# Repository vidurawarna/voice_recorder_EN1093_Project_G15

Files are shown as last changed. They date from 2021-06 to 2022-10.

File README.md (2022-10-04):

# voice_recorder_EN1093_Project_G15
Simple Voice Recorder is a simple tool to record multiple voice tracks and then play them back. The purpose of this project is to create a Simple Voice Recorder using theories of signal processing and information theory. The main objectives of this project are to record and save multiple voice recordings, selectively playback the recordings, and do minor adjustments to their spectrum during playback. Signal processing like frequency scaling and signal enhancement with low pass, band pass, and high pass filtering is carried out by using  MATLAB as a testing tool. (Relevant MATLAB codes can be found in the report.) An ATmega 328p chip was programmed with AVR. In this project, 8bit PCM (Pulse Code Modulation) is used for ADC ( Analog to Digital Conversion) and Fast PWM (Pulse Width Modulation) is used for DAC ( Digital to Analog Conversion).

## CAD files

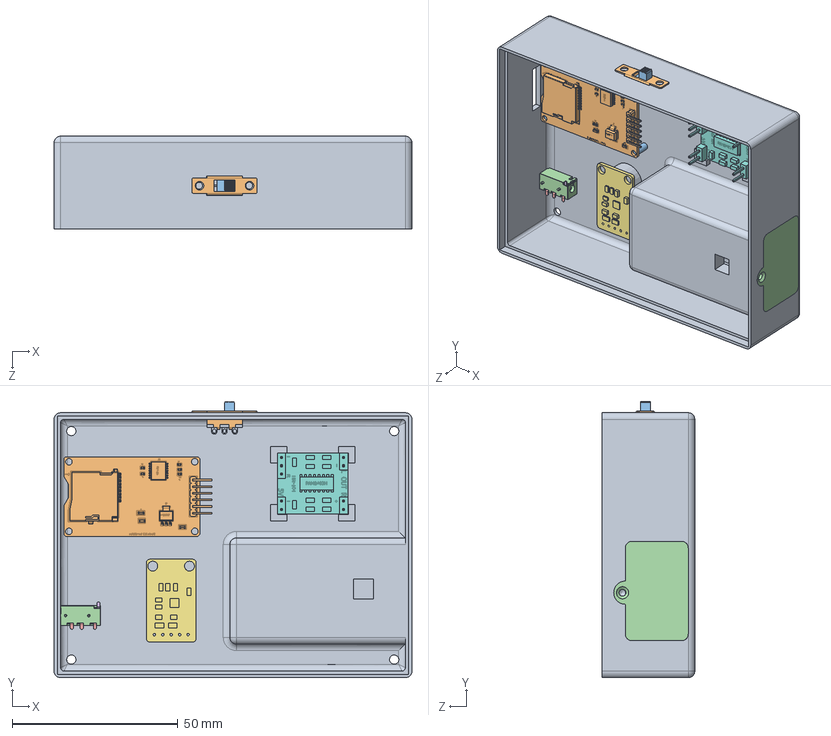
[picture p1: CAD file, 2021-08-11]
Enclosure and PCB/Enclosure Design/Assembled/Bottom Assembly.SLDASM
108.1 x 83.4 x 28.0 mm
Bottom Enclosure
Micro SD Module
SD Card Module Holder
PJ320A.STEP
PJ320D-Pin.STEP x 3
PJ320D-Pin-B.STEP
Microphone Module
Sound-Aplifier-Board-PAM8403-3W.stp
PCB.step
Housing.step
Switch.step
Battery Close Enclosure

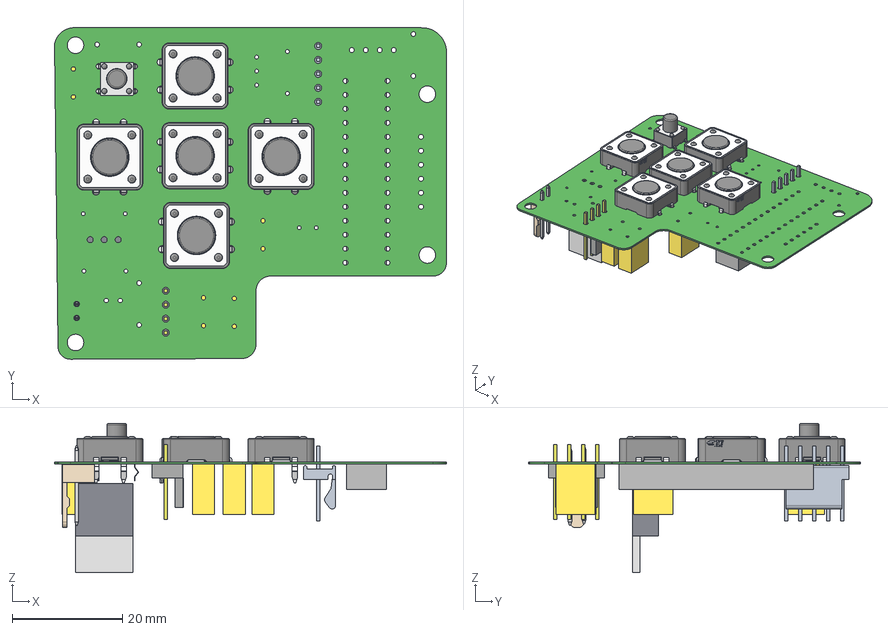
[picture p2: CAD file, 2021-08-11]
Enclosure and PCB/ALTIUM/EN1093 final/PCB_EN1093 1.step
71.2 x 60.2 x 27.1 mm
Extruded x 13
Switch_base
notches
Button
Pins
Panasonic
Leads x 5
Plastic x 5
Logo x 5
c-640456-5-aa-3d
6190xx11121_PIN x 2

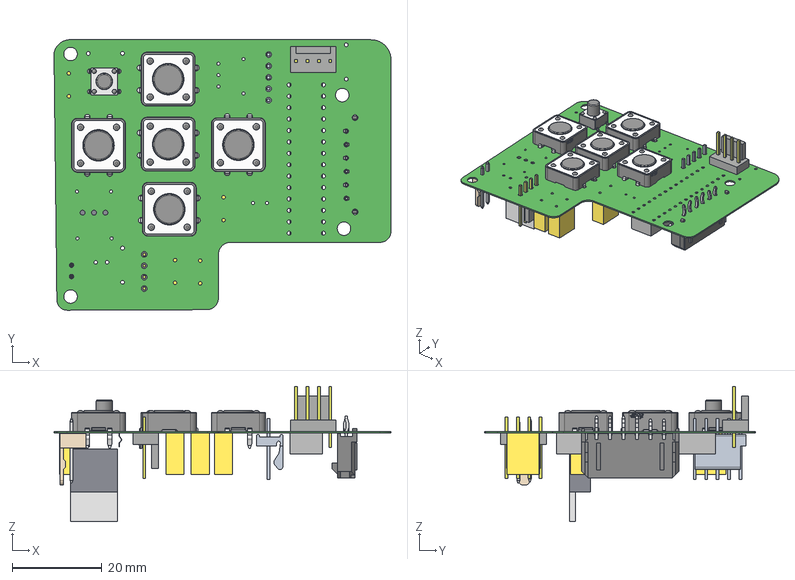
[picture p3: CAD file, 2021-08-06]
Enclosure and PCB/ALTIUM/EN1093 unrouted PCB for SolidWorks/PCB_EN1093.step
75.0 x 60.2 x 30.1 mm
6620xx11122_PIN x 6
Extruded x 19
Switch_base
notches
Button
Pins
Panasonic
Leads x 5
Plastic x 5
Logo x 5
c-640456-5-aa-3d
6190xx11121_PIN x 2

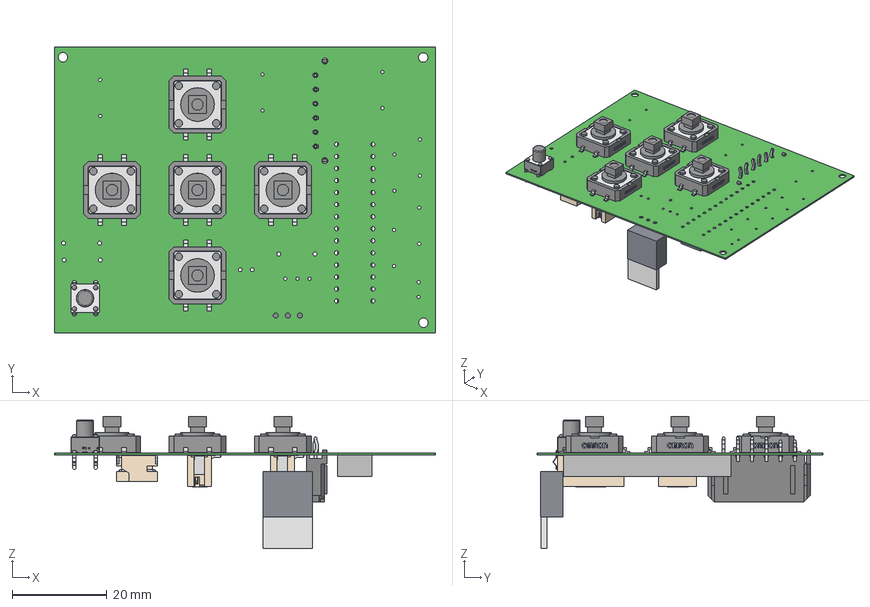
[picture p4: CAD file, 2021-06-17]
Enclosure and PCB/ALTIUM/EN1093 updated/PCB_EN1093_2.step
80.3 x 60.3 x 27.8 mm
Switch_base
notches
Button
Pins
Panasonic
IN x 5
Pads1 x 5
Pads2 x 5
Omron_Logo_Adjustable_Logo x 5
Extruded x 3
6203xx124022_PIN x 7
6203xx124022_Cap2
6203xx124022_PATTE x 4
6203xx124022_Cap1
6620xx11122_PIN x 6
6201xx131822_PIN x 8
6201xx131822_Solder_tab x 4

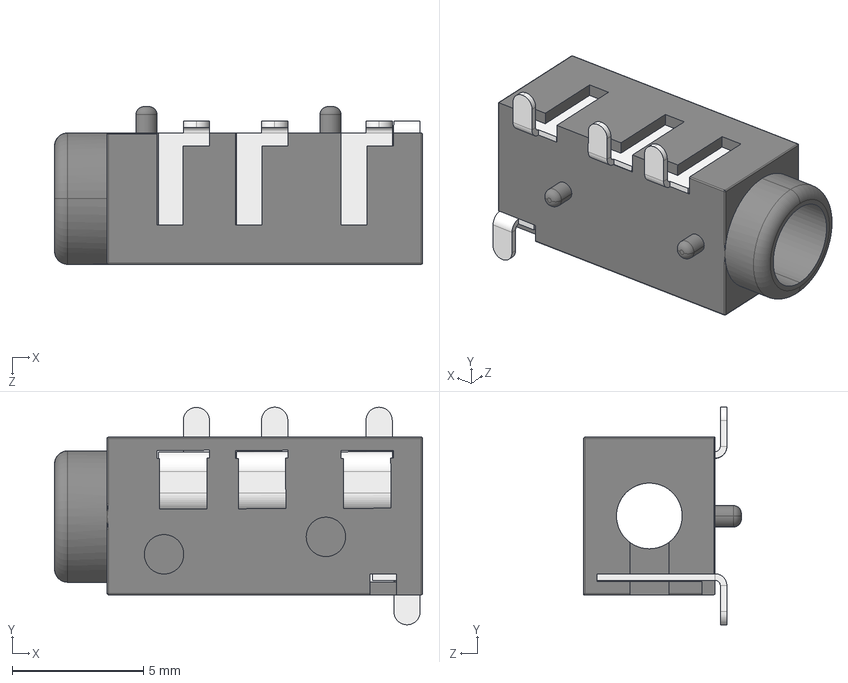
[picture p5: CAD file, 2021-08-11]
Enclosure and PCB/Enclosure Design/Modules/Jack.STEP
14.0 x 8.28 x 6.00 mm
PJ320A
PJ320D-Pin x 3
PJ320D-Pin-B

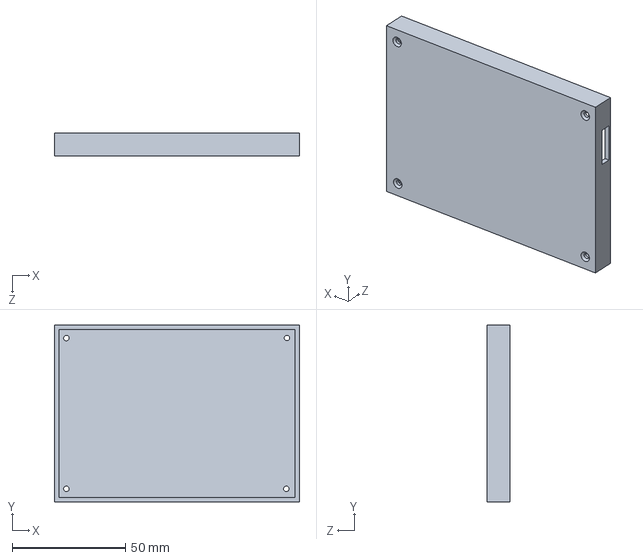
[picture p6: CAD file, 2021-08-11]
Enclosure and PCB/Enclosure Design/Enclosure/Bottom Enclosure.SLDPRT
108.1 x 78.0 x 10.0 mm

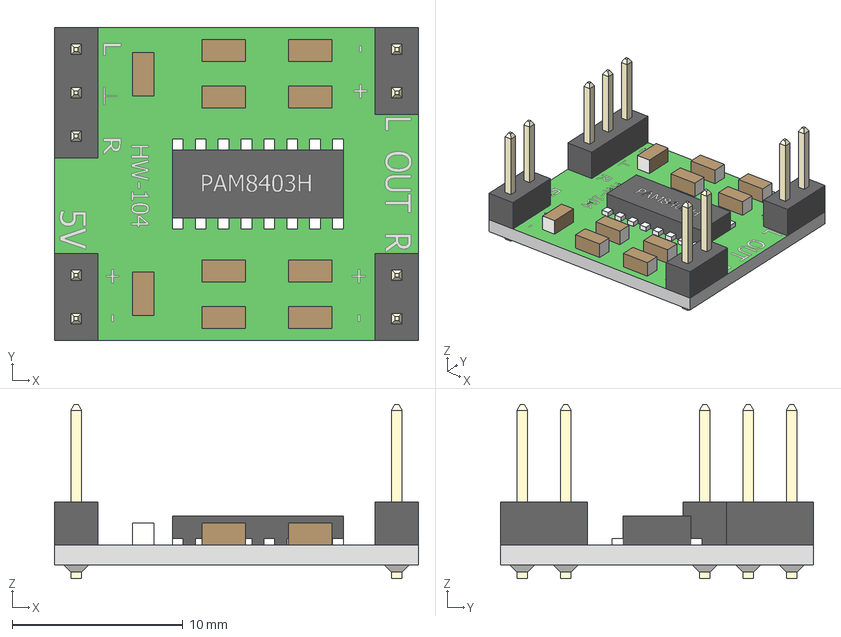
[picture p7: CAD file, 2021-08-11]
Enclosure and PCB/Enclosure Design/Modules/Sound Aplifier Board.stp
21.3 x 18.3 x 10.2 mm

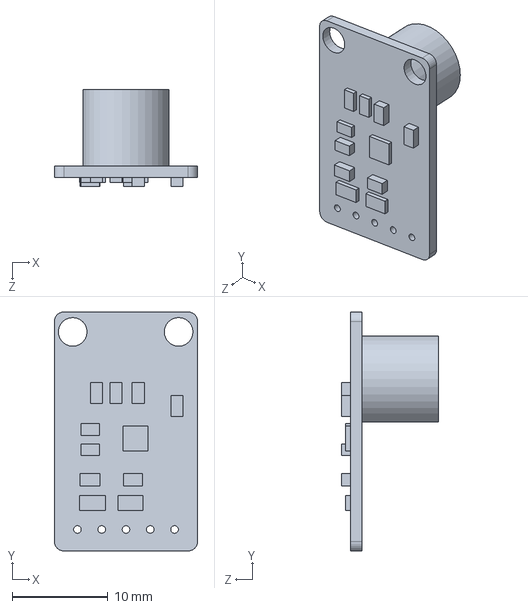
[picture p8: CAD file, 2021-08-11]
Enclosure and PCB/Enclosure Design/Modules/Microphone Module.SLDPRT
15.0 x 25.0 x 10.1 mm

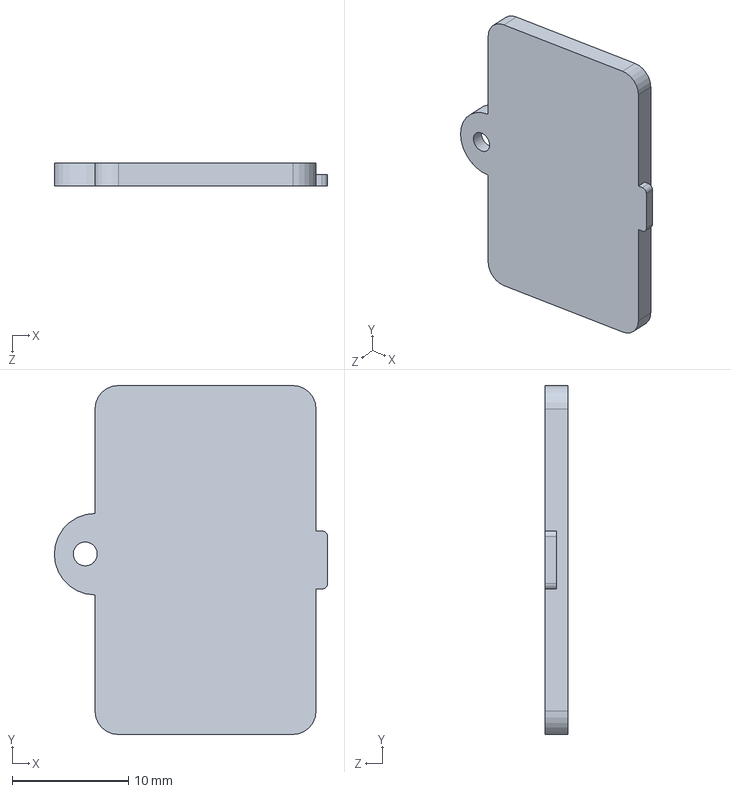
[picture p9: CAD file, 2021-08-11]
Enclosure and PCB/Enclosure Design/Enclosure/Battery Close Enclosure.SLDPRT
23.5 x 30.0 x 2.00 mm

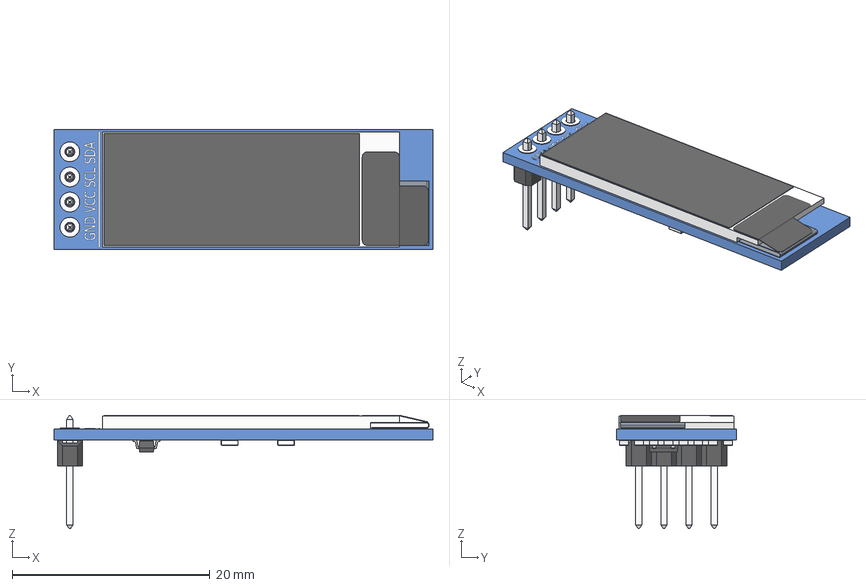
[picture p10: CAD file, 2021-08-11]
Enclosure and PCB/Enclosure Design/Modules/OLED LCD.stp
38.3 x 12.1 x 11.5 mm
OLED_0.91_128x32
Pin Header 4 x 1 TH 2.54mm Pitch
RESC-0603 x 13
2SD0601A

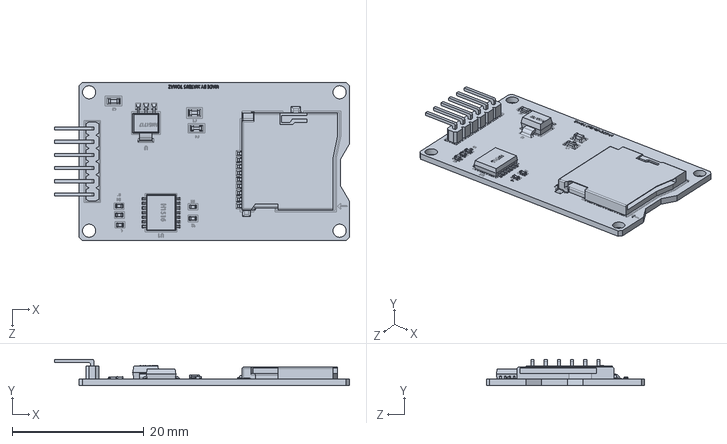
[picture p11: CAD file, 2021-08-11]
Enclosure and PCB/Enclosure Design/Modules/Micro SD Module.SLDPRT
44.7 x 4.00 x 24.0 mm

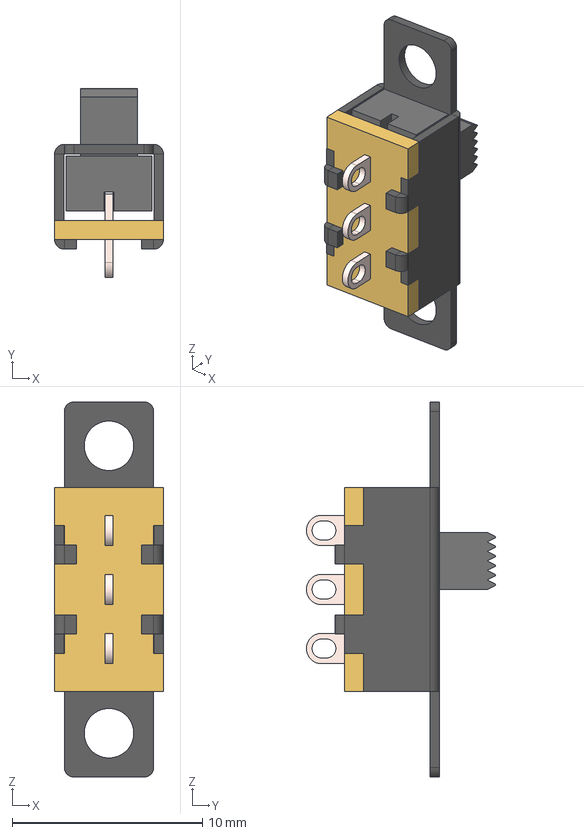
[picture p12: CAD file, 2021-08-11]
Enclosure and PCB/Enclosure Design/Modules/Mini Switch.step
5.72 x 9.94 x 19.7 mm
PCB
Housing
Switch

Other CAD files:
Enclosure and PCB/Enclosure Design/Enclosure/PCBEN10.step
Enclosure and PCB/ALTIUM/EN1093 final/PCB_EN1093.step
Enclosure and PCB/Enclosure Design/Enclosure/Key Pad Enclosure.SLDPRT
Enclosure and PCB/Enclosure Design/Enclosure/PCB_EN.step
Enclosure and PCB/Enclosure Design/Enclosure/Top Enclosure.SLDPRT
Enclosure and PCB/Enclosure Design/Modules/SD Card Module Holder.SLDPRT
Enclosure and PCB/Enclosure Design/Modules/Volume Knob Enclosure.SLDPRT

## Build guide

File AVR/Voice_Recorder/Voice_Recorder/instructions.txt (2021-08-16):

/*
 * instructions.txt
 *
 * Created: 6/15/2021 8:06:09 AM
 *  Author: Vidura
 */ 

[#] Conections:
 																													
+-------------+----------------------+------------+			
| Connection  | Arduino Uno/Nano pin | ATmega328p |		
+-------------+----------------------+------------+				
| MOSI (SD)   | pin 11               | PB3        |				
+-------------+----------------------+------------+				
| MISO (SD)   | pin 12               | PB4        |			
+-------------+----------------------+------------+			
| CLK (SD)    | pin 13               | PB5        |				
+-------------+----------------------+------------+				
| CS (SD)     | pin 10               | PB2        |				
+-------------+----------------------+------------+
| Mic         | pin A0               | PC0        |
+-------------+----------------------+------------+
| Speaker     | pin 9                | PB1        |	
+-------------+----------------------+------------+	
| LCD SCL     | pin A5               | PC5        |
+-------------+----------------------+------------+
| LCD SDA     | pin A4               | PC4        |
+-------------+----------------------+------------+
| Record      | pin 2                | PD2        |
+-------------+----------------------+------------+
| Play        | pin 5                | PD5        |
+-------------+----------------------+------------+
| Next        | pin 6                | PD6        |
+-------------+----------------------+------------+
| Previous    | pin 3                | PD3        |
+-------------+----------------------+------------+
| Delete	  |	pin 7				 | PD7        |
+-------------+----------------------+------------+

[#] Interface:

							                +-----+
							                |	  |<------------------/* Record/Stop
							                |     |					  \* Exit player
							                +-----+
					                +-----+ +-----+ +-----+
					                |	  | |	  | |	  |<-----------/* Next
                  Previous * \----->|     | |  <-\| |     |			   \* Filter 
Change the frequency scale * /		+-----+ +-----+\+-----+
			    			                +-----+ \-------------------/* Play/Stop
							                |	  |						\* 'No'
							                |     |<----\
							                +-----+      \--------------- * Delete

[#] How it works:

>>> When the device is powered up the screen looks like this. This is the pause state. No actions will happen. 
	+----------------+
	|Voice Recorder  |
	|                |
	+----------------+	
	>> If SD card is not inserted the device won't work. There will be a error message.
		+----------------+
		|Error           |
		|                |
		+----------------+
	>> Insert the SD card and power it up again.

>>> When in the pause state press 'Record' to start recording.
	+----------------+
	|Recording       |
	|                |
	+----------------+
	>> Press 'Recording' again to stop recording.
	+----------------+
	|saved           |
	|                |
	+----------------+

>>> When in the pause state press 'Play'. That will guide you to play mode.
	+----------------+
	|Ready to Play   |
	|A.WAV           |
	+----------------+

	>> If there are no valid recordings in the SD card It will give you a message and will go back to pause mode.
		(Valid means this device accepts recording names like A.WAV, B.WAV, ..., Z.WAV) 

		+----------------+
		|No Tracks       |
		|                |
		+----------------+

	>> Press 'Next' and 'Previous' to toggle between recordings. (Recordings will be in alphabatic order ie. A.WAV, B.WAV, ....)
	( Player holds only 15 recordings )

	>> Then press 'Play' again. It will bring you to the frequency change requirement checking mode.
	+----------------+
	|SCL  M          |
	| 1   X          |
	+----------------+

	>> Press 'Next' button to change 'M'(H, L, B, S, X) and press 'Previous' to change 'SCL'(1, 2, 3)
		> SCL - Frequency scale (Default = 1)
			* 1 - normal frequency
			* 2 - 2x frequency
			* 3 - 3x frequency
		> M - Filtering method (Default = 'X')
			* X - No filtering
			* H - High pass (cut off = 1000Hz)
			* L - Low pass (cut off = 500Hz)
			* B - Band pass (1000Hz - 2000Hz)
			* S - Frequency shift (1000Hz)

	>> After selecting frequency changes press 'Play' again.
		> If you didn't select any filters (M = X), the recording will play as you click play.
		> If You select value for M it will take some time to process the recording. After processing it will play.
			(Processed recording will be named by adding a prefix to the original wav file name. Prefixes- M values)

		+----------------+							+----------------+
		|Processing      |							|Playing         |
		|		         |							|A.WAV		     |
		+----------------+							+----------------+
		If 'M' is selected						    Playing the recording

		> If the device fails to open the file specified, it will give an error. 
			(Possible reasons will be SD card is removed before playing or unknown malfunction in firmware)
			+----------------+
			|Error           |
			|                |
			+----------------+

		> At the end of playing it will display a message. (Or you can press 'Play' when playing the recording to stop the play.)
		+----------------+
		|playing         |
		|End of Play     |
		+----------------+

	>>  When you are in the play mode you can delete the recording if you want. Press 'Delete' to proceeed. It will give you a prompt.
	+----------------+
	|Delete?         |
	|DELETE NO(Play) |
	+----------------+
		> Press 'Delete' again to proceed.
		+----------------+
		|Deleted         |
		|                |
		+----------------+
		> Press 'Play' to avoid deleting.
		+----------------+
		|Not Deleted     |
		|                |
		+----------------+

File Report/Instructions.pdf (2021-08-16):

1

# VOICE RECORDER

### Instructions for use

### ❖ Keypad

1 – Record / Stop Button

2 – Play / Stop Button – To play and stop the recordings, ‘No’ command in delete mode

3 – Previous Button – To load the previous recording, Selecting the frequency scale

4 – Next Button – To load the next recording, Selecting the filter

5 – Delete Button – Used to delete a recording

Additionally, there is a volume controller beside the keys.

### ❖ When the device is powered up the screen looks like this. This is the pause

state. No actions will happen.

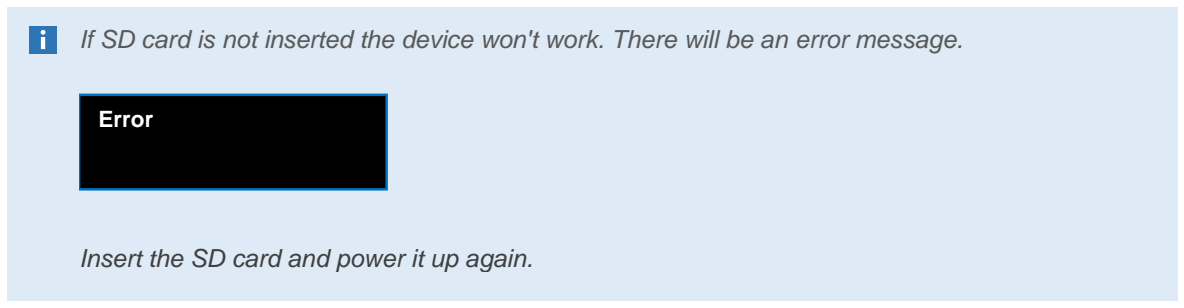
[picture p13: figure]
Error

If SD card is not inserted the device won't work. There will be an error message.

Insert the SD card and power it up again.

1

3 | 2 | 4

5

Voice Recorder

2

❖ When in the pause state press 'Record' to start recording.

Press 'Record' again to stop recording.

Do not remove the SD card while recording.

❖ When in the pause state press 'Play'. That will guide you to play mode.

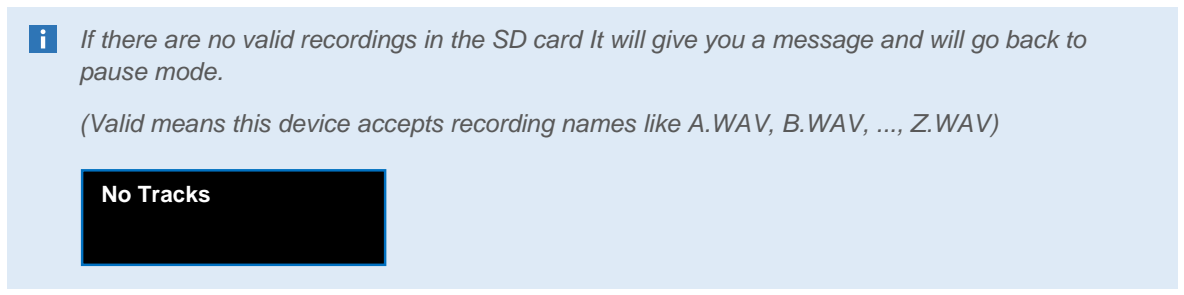
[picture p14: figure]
pause mode.; No Tracks

- Press 'Next' and 'Previous' to toggle between recordings. (Recordings will be in alphabetic order i.e.. A.WAV, B.WAV, ....,Z.WAV)
- Player holds only 15 recordings.
- Then press 'Play' again. It will bring you to the frequency change requirement checking mode.
- Press 'Next' button to change 'M'(H, L, B, S, X) and press 'Previous' to change 'SCL'(1, 2, 3)
- SCL - Frequency scale (Default = 1)
- 1 - normal frequency
- 2 - 2x frequency
- 3 - 3x frequency

If there are no valid recordings in the SD card It will give you a message and will go back to

(Valid means this device accepts recording names like A.WAV, B.WAV, ..., Z.WAV)

Recording

saved

Ready to Play

A.WAV

SCL M

1 X

3

- M - Filtering method (Default = 'X')
- X - No filtering
- H - High pass (cut off = 1000Hz)
- L - Low pass (cut off = 500Hz)
- B - Band pass (1000Hz - 2000Hz)
- S - Frequency shift (1000Hz)
- After selecting frequency changes press 'Play' again.
- If you didn't select any filters (M = X), the recording will play as you click play.
- If You select value for M it will take some time to process the recording. After processing it will play.

(Processed recording will be named by adding a prefix to the original wav file name. Prefixes- M values)

- At the end of play it will display a message. (Or you can press 'Play' when playing the recording to stop the play.)

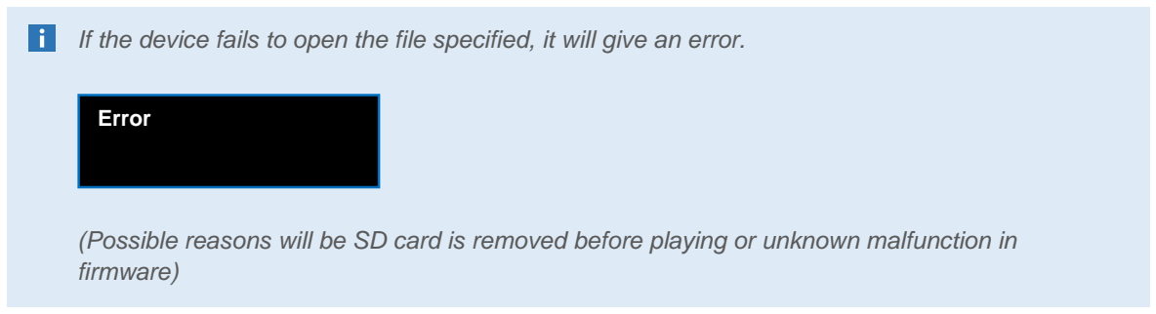
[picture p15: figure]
firmware); Error

If the device fails to open the file specified, it will give an error.

(Possible reasons will be SD card is removed before playing or unknown malfunction in

Processing | Playing A.WAV
If 'M' is selected | Playing the recording

Playing

End of Play

4

### ❖ When you are in the play mode you can delete the recording if you want. Press

'Delete' to proceed. It will give you a prompt.

Press 'Delete' again to proceed.

Press 'Play' to avoid deleting.

Delete?

DELETE NO(Play)

Deleted

Not Deleted

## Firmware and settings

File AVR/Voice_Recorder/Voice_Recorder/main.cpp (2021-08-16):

/*
 * Voice_Recorder.cpp
 *
 * Created: 6/5/2021 11:13:04 AM
 * Author : Vidura
 */ 

//>----------------- LIBRARIES -----------------<

#include <avr/io.h>
#include <util/delay.h>
#include <avr/interrupt.h>
#include <SD.h>
#include <SPI.h>
#include <Wire.h>
#include <LCDScreen.h>

//>----------- PIN  CONFIGURATIONS -------------<

#define mic 0b0000
#define sdcard 10

//>----------------- CALCULATIONS -----------------<

#define lower_Byte(w) ((uint8_t) ((w) & 0xff))
#define higher_Byte(w) ((uint8_t) ((w) >> 8))
#define sbi(port,bit) port |= 1<<bit

//>-------------- common values -------------------<

//Audio file attributes
#define sampleRate 12500
#define byteRate (sampleRate/8)*monoStereo*8
#define monoStereo 1
#define maxFiles 15
#define lcdAddr 0x20 //Change this to 0x20 for proteus simulation,0x27 for real application

//for filters
#define bufflen 26
#define temp_buff_size 75
#define coslen 13

/*latest code takes 80microsec to read a single data - 12.5kHz
   takes 80microsec to read and output one data - 12.5kHz
   (Updated 2021/5/26 6.07pm)
*/

//variables for mode
char mode = 'i';
char mode_ = 'j';

//variables for frequency changing configuration
uint8_t freqScal = 1;

//variables to handle file operations
char tracks[maxFiles];
uint8_t files = 0;
uint8_t fcount = 0;
char fname_temp[7];


//LCD screen instance
LCDScreen lcd(lcdAddr);

//functions used in recorder
char keyInput();

//functions for LCD
void firstLine(const char*);
void clrDisplay(const char*);
void secondLine(const char*);

//Recording,playing functions
void record();
void playTrack();
void checkChanges();
void getTrackList();
void nextTrack();
void previousTrack();
void checkDuplicates();
void deleteTrack();

//wave file creating functions
void makeWaveFile(File);
void finalizeWave(File);

//frequency modification functions
void pickFilter(char);
void convolve(int[],char[],uint8_t,int);
void sig_freqShift(char[]);

//IO functions
void initialize_Things();
uint8_t analog_in(int);


int main(void)
{	
	//This function is from arduino...need to edit
	initialize_Things();
	//sei();

	fname_temp[1] = '.';fname_temp[2] = 'W';fname_temp[3] = 'A';fname_temp[4] = 'V';

	//PORTD FOR KEYS
	DDRD = 0b00000000;
	PORTD = 0b11111111;
	
	//CONFIGURING PINS FOR ANALOG INPUT
	DDRC &= 0b11111110;	
	
	//CONFIGURING SPEAKER FOR OUTPUT
	DDRB |= (1<<DDB1);
	OCR1A = 0;
	
	//BEGIN THE LCD
	lcd.begin();
	
	//INITIALIZING THE SD CARD
	if (!SD.begin(sdcard))
	{
		clrDisplay("Error");
		while (1);
	}
	
	getTrackList();
	
	_delay_ms(1000);

    while (1) 
    {
		
		  //>-------------------------------< RECORD MODE (LEVEL 1)>--------------------------------<
		  if (mode == 's' && mode_ == 'j')
		  {
			record();
			getTrackList();
			mode = 'i';
		  }

		  //>--------------------------< ENTERING PLAYER MODE (LEVEL 1)>----------------------------<

		  if (mode == 'p' && mode_ == 'j')
		  {
			mode_ = 'k';
			mode = 'i';
			/*
			  This is the player mode
			  It loads the tracks in alphabetic order
			  Press 'Play/Stop' when a track is loaded to the player
			  Press 'Play/Stop' to stop playing
			  Press 'next' or 'previous' to toggle between tracks
			  Press 'record/stop' in track loaded mode to exit player mode
			*/
			if (files == 0)
			{
			  mode_ = 'j';
			  clrDisplay("No Tracks");
			  _delay_ms(1000);
			}
			else
			{
				clrDisplay("Ready to Play");
			  
			  _delay_ms(1000);
			  
			  fname_temp[0] = tracks[fcount];
			  secondLine(fname_temp);
			}
		  }
		  //>--------------------------< PLAYER MODE (LEVEL 2)>------------------------------------<
		  if (mode_ == 'k')
		  {
			  while (1)
			  {
				  char key_input = keyInput();
				  if (key_input)
				  {
					  mode = key_input;
					  break;
				  }
			  }
			if (mode == 'p')
			{
			  //Play the track
			  playTrack();
			  
			  clrDisplay("Ready to Play");

			}
			else if (mode == '>')
			{
			  //Load the next track
			  nextTrack();
			}
			else if (mode == '<')
			{
			  //load the previous track
			  previousTrack();
			}
			else if (mode == 's')
			{
			  //Exit from player mode
			  mode_ = 'j';
			  mode = 'i';
			}
			else if (mode == 'd')
			{
						  //This mode deletes the track loaded in payer
						  clrDisplay("Delete?");
						  secondLine("DELETE NO(Play)");
						  while (true)
						  {
							  char key = keyInput();
							  if (key && key == 'd')
							  {
								  deleteTrack();
								  clrDisplay("Deleted");
								  getTrackList();
								  
								  if(fcount == files){
									  fcount--;
								  }
								  
								  _delay_ms(1000);
								  break;
							  }
							  else if (key=='p')
							  {
								  clrDisplay("Not Deleted");
								  _delay_ms(1000);
								  break;
							  }
						  }

						  if (files == 0)
						  {
							  clrDisplay("No Tracks");
							  _delay_ms(1000);
							  mode_ = 'j';
						  }
						  else{
							  clrDisplay("Ready to Play");

							  fname_temp[0] = tracks[fcount];
						  }
			}
			secondLine(fname_temp);
			mode = 'i';
		  }
		  //>-------------------------< PAUSE MODE (LEVEL 1)>--------------------------------------<
		  if (mode == 'i' && mode_ == 'j')
		  {
			clrDisplay("Voice Recorder");
			while (1)
			{
				char key_input = keyInput();
				if (key_input)
				{
					mode = key_input;
					break;
				}
			}
		  }
    }
}

/*
   Definitions and implementations all the functions used in recorder
*/
//>-----------------------------------< KEYPAD FUNCTIONS >-------------------------------------<

char keyInput() {
  /*
    This function detects a key press and return the corresponding key
  */
  char k = 0;

  while (uint8_t m = ~PIND) {

    switch (m) {
      case 1: k = '_'; break;
      case 2: k = '*'; break;
      case 4: k = 's'; break;
      case 8: k = '<'; break;
      case 32: k = 'p'; break;
      case 64: k = '>'; break;
      case 128: k = 'd'; break;
      default: k = 0; break;
    }
    _delay_ms(300);
    PORTD = 0b11111111;

  }
  return k;
}

//END OF KEYPAD FUNCTIONS

//>--------------------------------< LCD DISPLAY FUNCTIONS >-----------------------------------<
void firstLine(const char *msg) {
  //Prints the string passed in the first line of the LCD display
  lcd.setCursor(0, 0);
  lcd.print(msg);
}

void clrDisplay(const char *msg) {
  //Clears the LCD and displays the msg in first line
  lcd.clear();
  lcd.setCursor(0, 0);
  lcd.print(msg);
}

void secondLine(const char *msg) {
  //Prints the string passed in the second line of the LCD display
  lcd.setCursor(0, 1);
  lcd.print(msg);
}

//END OF LCD DISPLAY FUNCTIONS

//>-----------------------------< RECORD AND PLAY FUNCTIONS >----------------------------------<

void record() {
	 /*Used to record the data got from input into a file*/
	  checkDuplicates();
	  File test_File = SD.open(fname_temp, FILE_WRITE);

	  if (!test_File) {
		clrDisplay("Error");
	  }
	  else {
		clrDisplay("Recording");
		makeWaveFile(test_File);
		uint8_t pot_Read;

		while (true) {
		
		  pot_Read = analog_in(mic);
		
		  char key = keyInput();

		  if (key && key == 's') {
			break;
		  }

		  test_File.write(pot_Read);
		  //_delay_us(8);//16kHz
		  _delay_us(28);// 12.5kHz

		}
		finalizeWave(test_File);
		clrDisplay("Saved");
		_delay_ms(1000);
	  }
	  test_File.close();
}

void playTrack()
{
  /*This function reads data from the specified file and play*/

  checkChanges();//check for frequency change requirements
clrDisplay("Playing");

  File test_File = SD.open(fname_temp);

  if (!test_File) {
    // if the file didn't open, print an error:
    secondLine("Error");
    _delay_ms(1000);
  }
  else {
    test_File.seek(44);
    
    secondLine(fname_temp);

    //Check whether a frequency scale is set
    //>---------------------------< NORMAL OUTPUT >----------------------------------<

    if (freqScal == 0 || freqScal == 1) {
      while (test_File.available()) {

        OCR1A = test_File.read();
		
        _delay_us(40);  //Use this delay for 12.5KHz play
        //_delay_us(16);    //Use this delay for 16kHz play
        
		//****Comment both of delays for 24kHz play*******
        
        char key = keyInput();
        if (key && key == 'p') {
          break;
        }
      }
    }

    //>---------------------------< SCALED OUTPUT >----------------------------------<
    //Output for freaquency scaled track
    //Using down sampling

    else {
      uint8_t count = 1;
      while (test_File.available()) {

        char key = keyInput();
        if (key && key == 'p') {
          break;
        }

        if (count == 1) {
          //Accept the first sample among (# of samples=freqScal)
		  OCR1A = test_File.read();
          
          _delay_us(40);  //Use this delay for 12.5KHz play
          //_delay_us(16);    //Use this delay for 16kHz play
          //Comment both of delays for 24kHz play

        } else {
          test_File.read();//This is to neglet samples in between
        }

        count++;

        if (count == freqScal + 1) {//resetting the count
          count = 1;
        }
      }
    }
    // close the file:

	OCR1A = 0;
    secondLine("End of play");
    test_File.close();
	    
  }
  _delay_ms(1000);
   fname_temp[0] = tracks[fcount];fname_temp[1] = '.';fname_temp[2] = 'W';fname_temp[3] = 'A';fname_temp[4] = 'V';fname_temp[5] = NULL;
}

void checkChanges() {
  /*
     This function checks for frequency change requirements
  */
	clrDisplay("SCL M");
	
	char fsc =49;
	char fshift='X';
	char row[6] = {' ',fsc,' ',' ',fshift};
		
	while(true){
		char key_input = keyInput();
		if (key_input=='p')
		{
			freqScal = uint8_t(fsc) - 48;
			break;
		}
		else if(key_input=='>'){
			if(fshift=='X'){
				fshift='H';
			}
			else if(fshift=='H'){
				fshift='L';
			}
			else if(fshift=='L'){
				fshift='B';
			}
			else if(fshift=='B'){
				fshift='S';
			}
			else if(fshift=='S'){
				fshift='X';
			}
		}
		else if(key_input=='<'){
			if(fsc==51){
				fsc=48;
			}
			fsc++;
		}
		row[1]=fsc;row[4]=fshift;
		secondLine(row);
	}
	
	if(fshift!='X'){
		  clrDisplay("Processing");
		  pickFilter(fshift);
	}
}
//END OF RECORD AND PLAY FUNCTIONS

//>--------------------------------------< FILE HANDLING FUNCTIONS >--------------------------------------<

void getTrackList() {
  /*
     This function checks for files and make a list of available files
     Program only accept 15 tracks
     counts the number of files
  */
  char ASCIIcount = 65;
  files = 0;
  
  fname_temp[0] = ASCIIcount;
  
  uint8_t arrIndex = 0;
  while (true) {
    if (arrIndex == maxFiles || ASCIIcount == 91) {
      break;
    }
    if (SD.exists(fname_temp)) {
      tracks[arrIndex++] = fname_temp[0];
      files++;
    }
	fname_temp[0] = ++ASCIIcount;
  }
  for (uint8_t i = arrIndex; i < maxFiles; i++) {
    tracks[i] = '_';
  }
}

void nextTrack() {
  /*
     Checks tracks in order and returns the next track
  */
  fcount++;
  if (tracks[fcount] == '_') {
    fcount = 0;
  }
  fname_temp[0] = tracks[fcount];
}

void previousTrack() {
  /*
     Checks tracks in order and returns the previous track
  */
  if (fcount == 0) {
    fcount = files - 1;
  }
  else
  {
    fcount--;
  }
  fname_temp[0] = tracks[fcount];
}

void checkDuplicates() {

  /*This function checks if the new file to be made is existing,
    if does it generates a new name for the file*/
  char count = 65;

  fname_temp[0] = count;
  while (true) {
    if (SD.exists(fname_temp)) {
	  fname_temp[0] = ++count;
    } else {
      break;
    }
  }
}

void deleteTrack(){
	/*
		Checks for depending files of the current file and delete them.
	*/
	SD.remove(fname_temp);

	fname_temp[0] = 'S';fname_temp[1] = tracks[fcount];fname_temp[2] = '.';fname_temp[3] = 'W';fname_temp[4] = 'A';fname_temp[5] = 'V';
	if(SD.exists(fname_temp)){SD.remove(fname_temp);}
	fname_temp[0] = 'H';
	if(SD.exists(fname_temp)){SD.remove(fname_temp);}
	fname_temp[0] = 'L';
	if(SD.exists(fname_temp)){SD.remove(fname_temp);}
	fname_temp[0] = 'B';
	if(SD.exists(fname_temp)){SD.remove(fname_temp);}
		
	fname_temp[0] = tracks[fcount];fname_temp[1] = '.';fname_temp[2] = 'W';fname_temp[3] = 'A';fname_temp[4] = 'V';fname_temp[5] = NULL;
}

//END OF FILE HANDLING FUNCTIONS

//>------------------------------< FUNCTIONS FOR WAVE FILE CREATION >---------------------------------<

void makeWaveFile(File sFile) {
  /*
     This function creates the wave header file required
     All bytes should be in little endian format, except String values
  */

  sFile.write((uint8_t*)"RIFF    WAVEfmt ", 16);//Starting bytes of the wave header file
  uint8_t chunk[] = {16, 0, 0, 0, 1, 0, 1, 0, lower_Byte(sampleRate), higher_Byte(sampleRate)};
  /*
     chunk[]
     first 4 bytes: size of  previous data chunck
     next 2 bytes: Audio format (1 - PCM)
     next 2 byte: No of channels (Mono = 1, Stereo = 2) (in our case 1)
     last two are the first two bytes of sample rate
  */
  sFile.write((uint8_t*)chunk, 10);

  chunk[0] = 0; chunk[1] = 0; //end of sample rate bytes

  //byteRate = (sampleRate/8)*monoStereo*8;
  chunk[2] = lower_Byte(byteRate); chunk[3] = higher_Byte(byteRate); chunk[4] = 0; chunk[5] = 0; // byteRate

  //byte blockAlign = monoStereo * (bps/8);
  //this is always equal to 1 in 8bit PCM mono channel
  chunk[6] = 1; chunk[7] = 0; //BlockAlign

  chunk[8] = 8; chunk[9] = 0; //bits per sample

  sFile.write((uint8_t*)chunk, 10);
  sFile.write((uint8_t*)"data    ", 8);

}

void finalizeWave(File sFile) {
  /*
     This function finalizes the wave file
  */
  unsigned long fSize = sFile.size();

  fSize -= 8;
  sFile.seek(4);
  uint8_t chunk2[4] = {lower_Byte(fSize), higher_Byte(fSize), fSize >> 16, fSize >> 24};
  sFile.write(chunk2, 4);//Writing chunksize to 5 - 8 bytes in wave file

  sFile.seek(40);
  fSize -= 36 ;
  chunk2[0] = lower_Byte(fSize); chunk2[1] = higher_Byte(fSize); chunk2[2] = fSize >> 16; chunk2[3] = fSize >> 24;
  sFile.write((uint8_t*)chunk2, 4);//Writting num of samples to 41-44 bytes in wave file
}
//END OF WAVE FILE CREATE FUNCTIONS


//>--------------------------------------< FREQUENCY CHANGES >--------------------------------------<
void sig_freqShift(char tempName[]) {
		
		File out = SD.open("temp.bin", FILE_WRITE);
		File target = SD.open(tempName, FILE_READ);
		target.seek(44);

		uint8_t buff[bufflen];
		//int16_t cosWave12_5[coslen] = {10, 10, 9, 7, 5, 3, 1, -2, -4, -6, -8, -9, -10, -10, -9, -8, -6, -4, -2, 1, 3, 5, 7, 9, 10};
		int16_t cosWave12_5[coslen] =	{10,8,5,0,-4,-8,-9,-9,-6,-1,3,7,9};
		uint8_t count = 0;
		uint8_t buffCount = 0;

		while (target.available()) {

			buff[buffCount++] = (uint8_t)((int)(target.read() - 127) * cosWave12_5[count++] / 10 + 127);
			if (count == coslen )
			{
				count = 0;
			}
			if (buffCount == bufflen) {
				buffCount = 0;
				out.write((uint8_t*)buff, bufflen);
			}
		}

		out.close();
		target.close();

}

void pickFilter(char M){
	
	char tempName[6] = {tracks[fcount],'.','W','A','V'};
	fname_temp[0] = M;fname_temp[1] = tracks[fcount];fname_temp[2] = '.';fname_temp[3] = 'W';fname_temp[4] = 'A';fname_temp[5] = 'V';
	
	if(!SD.exists(fname_temp)){
		if(M=='S' || M=='H'){

			//int filter[11] ={-18,-47,-83,-121,-148,833,-148,-121,-83,-47,-18};//kaiser 100fc beta1.8
			int filter[11] =	{-18,-46,-83,-120,-148,834,-148,-120,-83,-46,-18};//kaiser 1000fc beta1.84
			if(M=='S'){
				sig_freqShift(tempName);
				convolve(filter,tempName,11,500);
			}
			else{
				convolve(filter,tempName,11,500);
			}			
		}
		
		else if(M=='B'){
			//int filter[26] ={0,0,0,5,19,29,10,-44,-106,-121,-50,77,181,181,77,-50,-121,-106,-44,10,29,19,5,0,0,0};//bandpass Bar-hann 
			//int filter[15] ={14,-10,-71,-127,-107,12,164,233,164,12,-107,-127,-71,-10,14};//kaiser beta3 good
			int filter[11] =	{-69,-128,-109,13,170,242,170,13,-109,-128,-69};//kaiser beta1.9
			convolve(filter,tempName,11,500);		
		}
		else if(M=='L'){
			//int filter[14] ={66,68,70,72,73,74,74,74,74,73,72,70,68,66};
			int filter[12] =	{37,57,77,96,111,119,119,111,96,77,57,37};//KAISER BETA=-2
			convolve(filter,tempName,12,1000);
		}
	}
}

void convolve(int filter[],char tempName[],uint8_t filterlen,int divider) {
	/*
		Times that processing took:
		
			Band Pass: 1min 55sec for kaiser beta1.9
			Frequency shifting: 2min 45sec
			High pass: 1min 55sec
			Low pass: 1min 53sec
	*/
			
	uint8_t signal_in[filterlen];
	uint8_t temp_buff[temp_buff_size];
	float temp = 0;
	uint8_t temp_count = 0;
	File target;
			
	if(fname_temp[0]=='S'){target = SD.open("temp.bin", FILE_READ);}
	else{target = SD.open(tempName, FILE_READ);}
	File out = SD.open(fname_temp, FILE_WRITE);	
	makeWaveFile(out);
			
	unsigned long fSize = target.size();

	target.read(signal_in, filterlen);
	target.read(temp_buff, temp_buff_size);

	while (fSize) {

		if (temp_count == temp_buff_size) {
			target.read(temp_buff, temp_buff_size);
			temp_count = 0;
		}
		temp = 127;

		for (uint8_t i = 0; i < filterlen - 1; i++) {
			temp += ((float(signal_in[i]) - 127) * filter[i] / divider);
			signal_in[i] = signal_in[i + 1];
		}
		temp += ((float(signal_in[filterlen - 1]) - 127) * filter[filterlen - 1] / divider);
		signal_in[filterlen - 1] = temp_buff[temp_count++];

		out.write(uint8_t(temp));

		fSize --;
	}
	finalizeWave(out);
	out.close();
	target.close();
			
	if(SD.exists("temp.bin")){SD.remove("temp.bin");}	
}
//END OF FREQUENCY CHANGES


//>--------------------------------------< IO FUNCTIONS >--------------------------------------<
uint8_t analog_in(int inputPin = 0000){
		
	ADMUX |= inputPin;
	
	ADCSRA = ADCSRA | (1 << ADSC);
	while(ADCSRA & (1 << ADSC));
	
	ADMUX &= 0b11110000;
	
	return ADCH;
}

void initialize_Things()
{
	// this needs to be called before setup() or some functions won't
	// work there
	sei();
	
	// on the ATmega168, timer 0 is also used for fast hardware pwm
	// (using phase-correct PWM would mean that timer 0 overflowed half as often
	// resulting in different millis() behavior on the ATmega8 and ATmega168)
	sbi(TCCR0A, WGM01);
	sbi(TCCR0A, WGM00);
	
	// set timer 0 prescale factor to 64
	// this combination is for the standard 168/328/1280/2560
	sbi(TCCR0B, CS01);
	sbi(TCCR0B, CS00);
	
	// enable timer 0 overflow interrupt
	sbi(TIMSK0, TOIE0);
	
	// timers 1 and 2 are used for phase-correct hardware pwm
	// this is better for motors as it ensures an even waveform
	// note, however, that fast pwm mode can achieve a frequency of up
	// 8 MHz (with a 16 MHz clock) at 50% duty cycle
	TCCR1B = 0;
	
	//select no-prescaling
	//sbi(TCCR1B, CS11);
	sbi(TCCR1B, CS10);
	
	//select the Wave form generation mode as FAST PWM
	//select the non-inverting mode
	sbi(TCCR1A, WGM10);
	sbi(TCCR1A, COM1A1);
	sbi(TCCR1B, WGM12);
	
	// set timer 2 prescale factor to 64
	sbi(TCCR2B, CS22);
	
	// configure timer 2 for phase correct pwm (8-bit)
	sbi(TCCR2A, WGM20);
	
	// set a2d prescaler(16) so we are inside the desired 50-200 KHz range.
	sbi(ADCSRA, ADPS2);
	//sbi(ADCSRA, ADPS1);
	//sbi(ADCSRA, ADPS0);
	
	// enable a2d conversions
	sbi(ADCSRA, ADEN);
	
	//set the reference voltage as AVCC
	//set the Left adjust result
	//keeping last 3bits as 0, because for the default pin selection as ADC0
	ADMUX = 0b01100000;
	
	// the bootloader connects pins 0 and 1 to the USART; disconnect them
	// here so they can be used as normal digital i/o; they will be
	// reconnected in Serial.begin()
	UCSR0B = 0;
}
//END OF IO FUNCTIONS

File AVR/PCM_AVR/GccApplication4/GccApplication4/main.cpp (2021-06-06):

/*
 * GccApplication4.cpp
 *
 * Created: 6/3/2021 7:19:43 PM
 * Author : nusha
 */ 

#define F_CPU 1000000UL
#include <avr/io.h>
#include <util/delay.h>


void analogRead_config(){
	//set all the port C pins as output because port c contains all the ADC pins
	DDRC = 0b00000000;
	
	//set the reference voltage as AVCC
	//set the Left adjust result
	//keeping last 3bits as 0, because for the default pin selection as ADC0
	ADMUX = 0b01100000;
	
	//enable the ADC
	//set the ADC pre scaler as 16
	ADCSRA = 0b10000100;
}
int analogRead(int inputPin = 0000){

	//change or select the ADC pin
	ADMUX |= inputPin;
	
	//start the ADC conversion
	ADCSRA = ADCSRA | (1 << ADSC);
	
	//wait until the ADSC bit has been cleared
	while(ADCSRA & (1 << ADSC));
	
	//this will return the 8-bit value
	return ADCH;
}

//this analog write function write on the pin OCA0
void analogWrite_config(){
	//select the Wave form generation mode as FAST PWM
	//select the non-inverting mode
	TCCR0A |= (1<<WGM00)|(1<<COM0A1)|(1<<WGM01);
	
	//select no-prescaling
	TCCR0B |= (1<<CS00);
	
	//set OCA0 pin as a output
	DDRD |= (1<<DDD6);
}
void analogWrite_config2(){
	TCCR1A |= (1<<WGM10) | (1<<COM1A1);
	TCCR1B |= (1<<WGM12) | (1<<CS10);
	
	DDRB |= (1<<DDB1);
}
int main(void)
{
	analogRead_config();
	analogWrite_config2();
	while (1)
	{
		
		OCR1A = analogRead();
	}
}

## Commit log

2021-04-20 file duplication fixed, feature improvements
    [functions.ino]
2021-04-20 seperated functions for lcd arduino simulations
2021-04-20 added I2C display files
2021-04-25 Edited pin configurarion .h file and library including
2021-04-26 Combined speaker output circuit
2021-05-04 Speaker output circuit modified
2021-05-18 An arduino code for filters
2021-05-22 dac using filter files added
2021-05-22 filter resister values changed
2021-05-22 Main loop changed, created two mode levels
    [configuration.h]
2021-05-24 Speaker added to PWM-DAC
2021-05-26 Added arduino test directory, changed functions to reduce memory usage
    [configuration.h]
2021-05-26 Analog read made faster, NEW SAMPLE RATE=12.5kHz, Separate pins for keys
    [configuration.h]
2021-05-29 Frequency shifting code is avaialable in arduino test
    [configuration.h]
2021-06-01 A simulation for real implementation is added in Arduino test directory
    [configuration.h]
2021-06-01 avr pcm-adc and dac simulation files added
2021-06-02 AVR and Enclosure,PCB directories added
2021-06-05 AVR code added, freaquency scaling(convolution) code implemented
    [configuration.h]
2021-06-06 avr pcm code modification for arduino pin 9
2021-06-06 commit before pulling 06/06 12.10pm
    [configuration.h]
2021-06-09 arduino init() code coverted to avr
2021-06-09 arduino init() code coverted to avr(comments edited)
2021-06-09 Unnecessory libs of AVR code are removed,Variables changed, Filter function not working well in AVR
    [LCDScreen.cpp, functions.ino, main.cpp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]
2021-06-09 corrections in arduino code
    [functions.ino, recorder.ino]
2021-06-10 Filter codes fixed,Library include modified
    [configuration.h]
2021-06-11 Filter codes fully implemented, removed the use of POTs and added a new mode level to do frequency changes
2021-06-12 Filter coefficients changed for better outcome
2021-06-15 alternative altium PCB files added
    [EN1093.PrjPcb, PCB_EN1093.PcbDoc, PCB_EN1093.step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]
2021-06-17 updated altium PCB files added
    [PCB_EN1093.PcbDoc, PCB_EN1093.step, PCB_EN1093_2.step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]
2021-06-21 modified pcb with 6 holes for mounting
    [Copy of PCB_EN1093.PcbDoc, Copy of PCB_EN1093.step, PCB_EN1093.PcbDoc]
2021-06-22 replaced holes
    [Copy of PCB_EN1093.PcbDoc, Copy of PCB_EN1093.step]
2021-06-24 KeyInput function modified to work when button is released, Changes in simulation
2021-08-03 Corrected some clearances in the PCB
    [Copy of PCB_EN1093.PcbDoc, PCB_EN1093.PcbDoc]
2021-08-04 updated the PCB design
    [Copy of PCB_EN1093.PcbDoc, Copy of PCB_EN1093.step, EN1093.PrjPcb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]
2021-08-04 Modified PCB for OLED
    [Copy of PCB_EN1093.PcbDoc, Copy of PCB_EN1093.step, PCB_EN1093.PcbDoc]
2021-08-04 updated the PCB design with the step file for solidworks
    [Copy of PCB_EN1093.PcbDoc, EN1093.PrjPcb, PCB_EN1093.PcbDoc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]
2021-08-05 Gerber files added
    [EN1093.PrjPcb, PCB_EN1093.PcbDoc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]
2021-08-06 updated the PCB design with the step file for solidworks with some changes for oled
    [Copy of PCB_EN1093.PcbDoc, EN1093.PrjPcb, PCB_EN1093.PcbDoc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]
2021-08-09 added some hole adjustment for pcb
    [PCB_EN1093.PcbDoc]
2021-08-09 oled mounting header changed
    [PCB_EN1093.PcbDoc, Sheet1.SchDoc]
2021-08-10 mounting header changed
    [PCB_EN1093.PcbDoc, PCB_EN1093.step, Sheet1.SchDoc]
2021-08-11 Final Enclosure Design
    [Battery Close Enclosure.SLDPRT, Bottom Assembly.SLDASM, Bottom Enclosure.SLDPRT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]
